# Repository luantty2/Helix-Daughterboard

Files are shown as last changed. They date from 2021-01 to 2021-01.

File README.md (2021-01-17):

## Helix Daughterboard
The helix daughterboard is a USB breakout board designed specifically for keyboards. The board integrates 11 components in a relatively small-sized PCB, and it's able to provide full protection for USB2.0 interface.

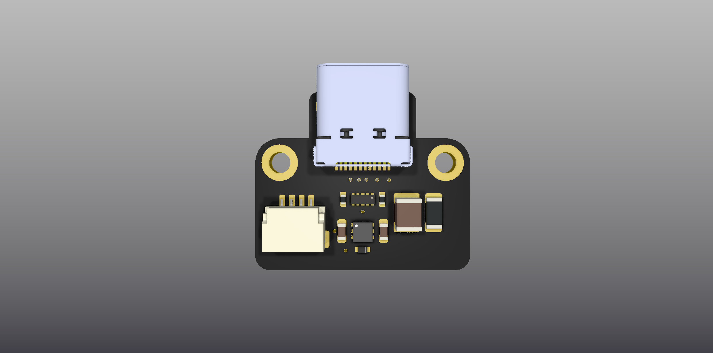
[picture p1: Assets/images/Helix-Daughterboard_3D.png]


### FEATURES

* IEC 61000-4-2 Level 4 ESD Protection
* VBUS UVLO, OVLO, OCP

### DEATILS

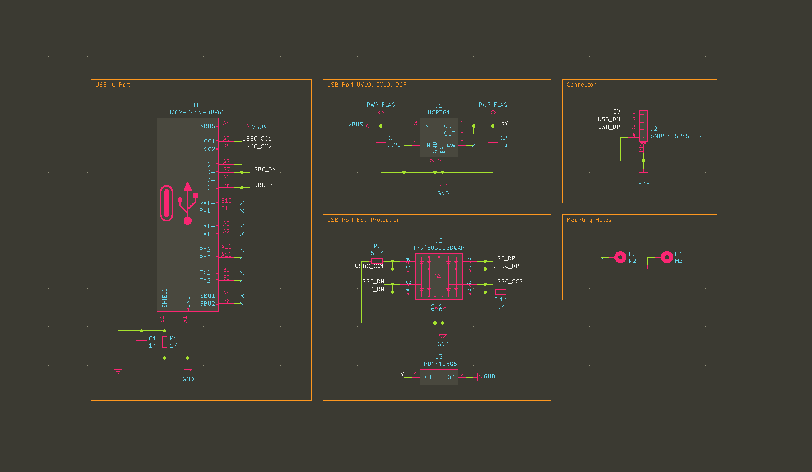
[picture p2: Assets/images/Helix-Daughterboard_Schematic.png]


* J1 is the USB3.0 receptacle with a row of through-hole data pins, with which the receptacle can be soldered much more firmly. In addition, C1 must have the rated voltage ≥2KV.

* U1 is the ONsemi NCP361, which is a single-chip solution for Undervoltage Lockout(UVLO), Overvoltage Lockout(OVLO) and Overcurrent Protection(OCP). 

    The overvoltage lockout threshold is typically 5.675V and overcurrent limit is internally set to 750mA. 

    The NCP361 itself complies to IEC61000−4−2 (Level 4), so place the device before U3 to keep VBUS voltage not violating TPD1E10B06's DC breakdown voltage(±6V).

* U2 is TPD4E05U06 ESD and surge protection chip for USB data lines and CC pins.

* U3 is TPD1E10B06 ESD and surge protection chip for VBUS power.

* H1 and H2 are screw mounting holes, one of them is connected to USB shield.

### BOM

| Designator  | Comment | Package | LCSC PN |
| --- | --- | --- | --- |
| C1 | 1nF | 1210 | C173219
| C2 | 2.2uF | 0603 | C342993
| C3 | 1uF | 0603 | C76619
| J2 | SM04B-SRSS-TB | - | C160404
| R1 | 1M | 1206 | C205050
| R2, R3 | 5.1K | 0402 | C203181
| U1 | NCP361 | UDFN-6 | C233713
| U2 | TPD4E05U06DQAR  | USON-10 | C138714
| U3 | TPD1E10B06 | X1SON-2 | C48260
| J1 | U262-241N-4BV60 | - | C388659

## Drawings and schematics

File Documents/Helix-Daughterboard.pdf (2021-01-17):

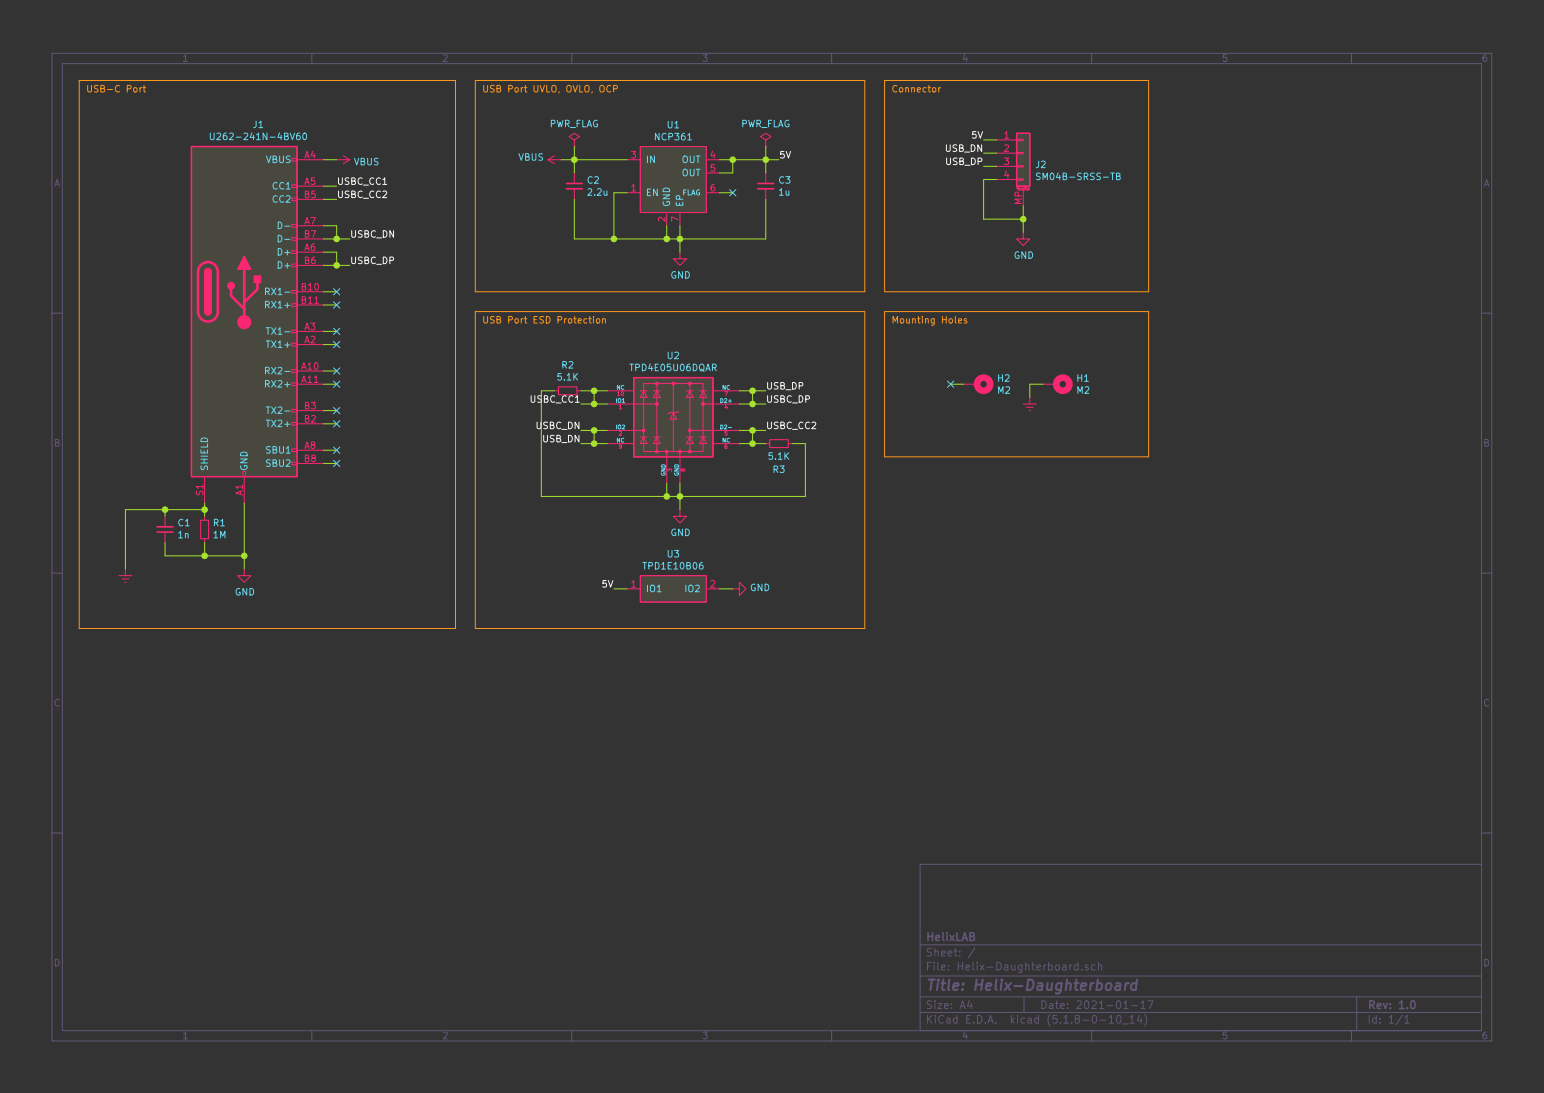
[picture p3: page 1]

File: Helix-Daughterboard.sch Sheet: / HelixLAB

Id: 1/1 Title: Helix-Daughterboard

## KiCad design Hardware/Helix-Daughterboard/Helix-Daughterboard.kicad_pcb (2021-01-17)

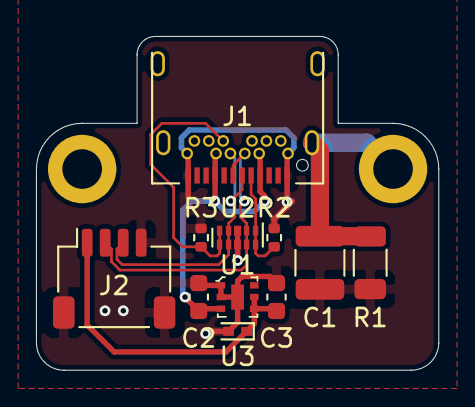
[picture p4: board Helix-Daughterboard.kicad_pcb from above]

Board: 2 copper layers, 22.4 x 18.5 mm, 13 parts (0 on the bottom side), 8 nets.

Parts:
C1: 1n; C_1210_3225Metric
C2: 2.2u; C_0603_1608Metric
C3: 1u; C_0603_1608Metric
H1, H2: M2; MountingHole_2.2mm_M2_DIN965_Pad
J1: U262-241N-4BV60; USB3_C_Receptacle_HRO
J2: SM04B-SRSS-TB; JST_SH_SM04B-SRSS-TB_1x04-1MP_P1.00mm_Horizontal
R1: 1M; R_1206_3216Metric
R2, R3: 5.1K; R_0402_1005Metric
U1: NCP361; UDFN-6-1EP_2x2mm
U2: TPD4E05U06DQAR; USON-10_2.5x1.0mm_P0.5mm
U3: TPD1E10B06; X1SON-2

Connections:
/5V: C3.1, J2.1, U1.4, U1.5, U3.1
/USBC_CC1: J1.A5, R2.1, U2.1, U2.10
/USBC_CC2: J1.B5, R3.1, U2.5, U2.6
/USBC_DN: J1.A7, J1.B7, J2.2, U2.2, U2.9
/USBC_DP: J1.A6, J1.B6, J2.3, U2.4, U2.7
Earth: C1.2, H2.1, J1.S1, R1.2
GND: C1.1, C2.2, C3.2, J1.A1, J1.A12, J1.B1, J1.B12, J2.4, J2.MP, R1.1, R2.2, R3.2, U1.1, U1.2, U1.7, U2.3, U2.8, U3.2
VBUS: C2.1, J1.A4, J1.A9, J1.B4, J1.B9, U1.3
